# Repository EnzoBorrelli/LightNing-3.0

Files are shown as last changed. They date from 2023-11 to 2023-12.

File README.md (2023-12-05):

# LightNing 3.0

This is the 3rd version of my esp32 + Dualshock4® Rc car, it has the pc made entirely out of smd pieces

## Installation

Download the files. Install KiCad for the PCB and any arduino code editor of your preference (I use Arduino IDE)

## Usage
In the IDE, you must install the ESP32 board and the bluepad 32 library:
[How to install](https://github.com/ricardoquesada/bluepad32#how-to-compile-it)
[original repo](https://github.com/ricardoquesada/bluepad32#bluepad32)

## Contributing

Pull requests are welcome. For major changes, please open an issue first
to discuss what you would like to change.

Please make sure to update tests as appropriate.

## License

[MIT](https://choosealicense.com/licenses/mit/)

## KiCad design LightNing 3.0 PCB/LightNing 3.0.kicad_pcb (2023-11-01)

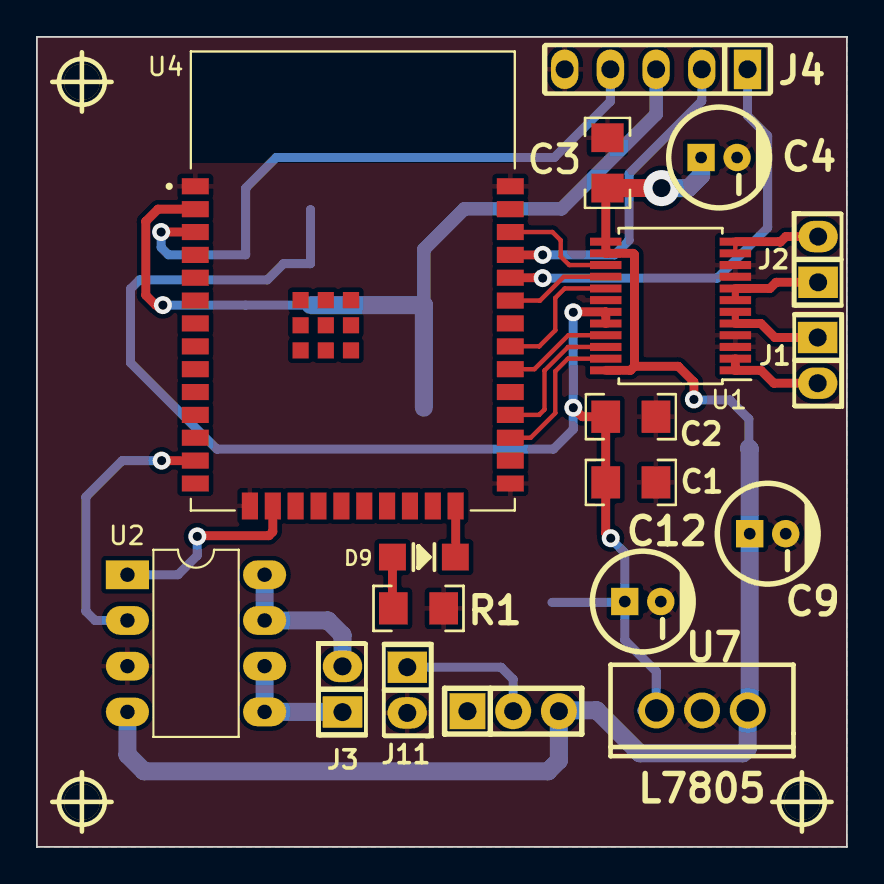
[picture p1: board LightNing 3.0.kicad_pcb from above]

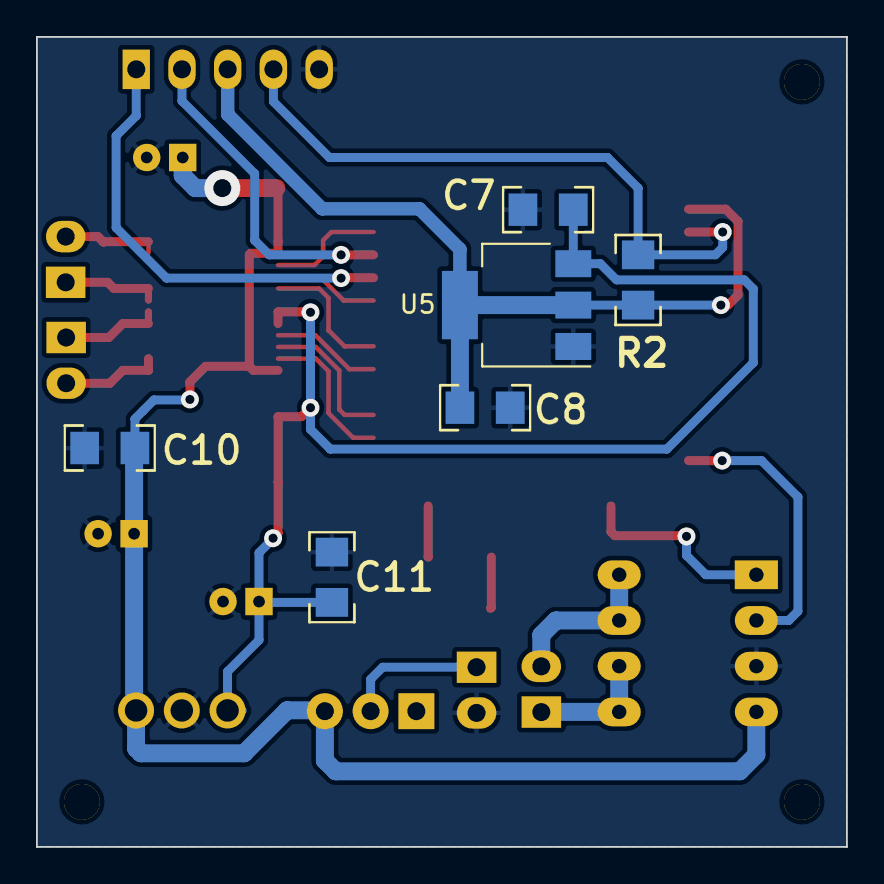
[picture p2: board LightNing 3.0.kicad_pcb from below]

Board: 2 copper layers, 45.0 x 45.0 mm, 27 parts (6 on the bottom side), 24 nets.

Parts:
C1, C3, C7: 10uF; C_1206
C2, C10, C11: 100nF; C_1206
C4: 22uF 25v; CAP_ELEC_5x11mm
C8: 22uF; C_1206
C9: 100uF 25v; CAP_ELEC_5x11mm
C12: 10uF 16v; CAP_ELEC_5x11mm
D9: LED; LED_1206
J1: motor izq; Pin_Header_2
J2: motor der; Pin_Header_2
J3: motor dir; Pin_Header_2
J4: programmer; Pin_Strip_5
J11: batt; Pin_Header_2
R1: 220; R_1206
R2: 10k; R_1206
SW2: SW_SPDT; Pin_Strip_3
U1: TB6612FNG; SSOP-24_5.3x8.2mm_P0.65mm
U2: TA6586; DIP-8
U4: ESP32-WROOM-E; XCVR_ESP32-WROOM-32E__16MB_
U5: AMS1117-3.3; SOT-223-3_TabPin2
U7: L7805; TO-220
hole_2mm, hole_2mm#2, hole_2mm#3: VAL**; hole_2mm

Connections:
+3.3V: C8.1, J4.3, R2.1, U4.2 (3V3), U5.2 (VO)
+5V: C1.1, C2.1, C7.1, C11.1, C12.1, U1.19 (STBY), U1.20 (VCC), U5.3 (VI), U7.3 (OUT)
/IN1: U1.21 (AIN1), U4.30 (GPIO18)
/IN2: U1.22 (AIN2), U4.28 (GPIO17)
/IN3: U1.17 (BIN1), U4.31 (GPIO19)
/IN4: U1.16 (BIN2), U4.33 (GPIO21)
/PWA: U1.23 (PWMA), U4.27 (GPIO16)
/PWB: U1.15 (PWMB), U4.36 (GPIO22)
/en: J4.4, R2.2, U4.3 (EN/CHIP_PU)
/pin_dirA: U2.2 (FI), U4.13 (MTMS/GPIO14/ADC2_CH6)
/pin_dirB: U2.1 (BI), U4.16 (MTCK/GPIO13/ADC2_CH4)
/rx: J4.1, U4.34 (U0RXD/GPIO3)
/tx: J4.2, U4.35 (U0TXD/GPIO1)
GND: C1.2, C2.2, C3.2, C4.2, C7.2, C8.2, C9.2, C10.2, C11.2, C12.2, J4.5, J11.2, R1.2, U1.3 (PGND1), U1.4 (PGND1), U1.9 (PGND2), U1.10 (PGND2), U1.18 (GND), U2.3 (GND), U4.1 (GND), U4.15 (GND), U4.25 (GPIO0/BOOT/ADC2_CH1), U4.38 (GND), U5.1 (GND), U7.2 (GND)
unnamed: D9.2 (A), U4.24 (ADC2_CH2/GPIO2)
unnamed: D9.1 (K), R1.1
unnamed: J1.1, U1.5 (AO2), U1.6 (AO2)
unnamed: J1.2, U1.1 (AO1), U1.2 (AO1)
unnamed: J2.1, U1.7 (BO2), U1.8 (BO2)
unnamed: J2.2, U1.11 (BO1), U1.12 (BO1)
unnamed: J3.1, U2.5 (FO), U2.6 (FO)
unnamed: J3.2, U2.7 (BO), U2.8 (BO)
unnamed: J11.1, SW2.2 (B)
VCC: C3.1, C4.1, C9.1, C10.1, SW2.3 (C), U1.13 (VM2), U1.14 (VM3), U1.24 (VM1), U2.4 (VCC), U7.1 (IN)

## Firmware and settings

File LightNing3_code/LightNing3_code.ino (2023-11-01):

/*
----LightNing 3.0 code V1----

codigo de control del RC-car, comunicando el NODEMcu-esp32s con DualSHock4®

- ByEnder|2023

*/
#include <Adafruit_NeoPixel.h>
#include <Bluepad32.h>

//Librerias propias
#include "Defines.h"
#include "motorClass.h"

#define DEBUG true
//constantes de giro
#define JOYSTICK_DEADZONE 70
#define PWM_LOST 50

// constante de velocidad
#define NORMAL_SPEED 200

//inicializacion de los objetos de los motores
Motor *LadoIZQ = new Motor(PWM_MOTOR_A, PIN_PWM1, PIN_MOTOR_A1, PIN_MOTOR_A2, FREQ, RES);
Motor *LadoDER = new Motor(PWM_MOTOR_B, PIN_PWM2, PIN_MOTOR_B1, PIN_MOTOR_B2, FREQ, RES);

GamepadPtr myGamepads[BP32_MAX_GAMEPADS];

// This callback gets called any time a new gamepad is connected.
// Up to 4 gamepads can be connected at the same time.
void onConnectedGamepad(GamepadPtr gp) {
  bool foundEmptySlot = false;
  for (int i = 0; i < BP32_MAX_GAMEPADS; i++) {
    if (myGamepads[i] == nullptr) {
      Serial.printf("CALLBACK: Gamepad is connected, index=%d\n", i);
      // Additionally, you can get certain gamepad properties like:
      // Model, VID, PID, BTAddr, flags, etc.
      GamepadProperties properties = gp->getProperties();
      Serial.printf("Gamepad model: %s, VID=0x%04x, PID=0x%04x\n",
                    gp->getModelName().c_str(), properties.vendor_id,
                    properties.product_id);
      myGamepads[i] = gp;
      foundEmptySlot = true;
      break;
    }
  }
  if (!foundEmptySlot) {
    Serial.println(
      "CALLBACK: Gamepad connected, but could not found empty slot");
  }
}

void onDisconnectedGamepad(GamepadPtr gp) {
  bool foundGamepad = false;

  for (int i = 0; i < BP32_MAX_GAMEPADS; i++) {
    if (myGamepads[i] == gp) {
      Serial.printf("CALLBACK: Gamepad is disconnected from index=%d\n", i);
      myGamepads[i] = nullptr;
      foundGamepad = true;
      break;
    }
  }

  if (!foundGamepad) {
    Serial.println(
      "CALLBACK: Gamepad disconnected, but not found in myGamepads");
  }
}
// Arduino setup function. Runs in CPU 1
void setup() {
  ledNeo.begin();
  if (DEBUG) Serial.begin(115200);
  Serial.printf("Firmware: %s\n", BP32.firmwareVersion());
  const uint8_t *addr = BP32.localBdAddress();
  Serial.printf("BD Addr: %2X:%2X:%2X:%2X:%2X:%2X\n", addr[0], addr[1], addr[2],
                addr[3], addr[4], addr[5]);

  // Setup the Bluepad32 callbacks
  BP32.setup(&onConnectedGamepad, &onDisconnectedGamepad);

  // "forgetBluetoothKeys()" should be called when the user performs
  // a "device factory reset", or similar.
  // Calling "forgetBluetoothKeys" in setup() just as an example.
  // Forgetting Bluetooth keys prevents "paired" gamepads to reconnect.
  // But might also fix some connection / re-connection issues.
  BP32.forgetBluetoothKeys();
}

// Arduino loop function. Runs in CPU 1
void loop() {
  // This call fetches all the gamepad info from the NINA (ESP32) module.
  // Just call this function in your main loop.
  // The gamepads pointer (the ones received in the callbacks) gets updated
  // automatically.
  BP32.update();
  ledNeo.clear();
  // It is safe to always do this before using the gamepad API.
  // This guarantees that the gamepad is valid and connected.
  for (int i = 0; i < BP32_MAX_GAMEPADS; i++) {
    GamepadPtr myGamepad = myGamepads[i];

    if (myGamepad && myGamepad->isConnected()) {
      myGamepad->setColorLED(white[0], white[1], white[2]);
      if (myGamepad->throttle()) {
        LadoIZQ->MotorUp(NORMAL_SPEED);
        LadoDER->MotorUp(NORMAL_SPEED);
        myGamepad->setColorLED(green[0], green[1], green[2]);
        if (DEBUG) Serial.println("pa lante");
      }
      if (myGamepad->brake()) {
        LadoIZQ->MotorDown(NORMAL_SPEED);
        LadoDER->MotorDown(NORMAL_SPEED);
        myGamepad->setColorLED(orange[0], orange[1], orange[2]);
        if (DEBUG) Serial.println("pa atras");
      }
      if (myGamepad->axisX()) {
        if (myGamepad->axisX() < -JOYSTICK_DEADZONE) {
          LadoIZQ->MotorUp(NORMAL_SPEED - PWM_LOST);
          LadoDER->MotorUp(NORMAL_SPEED);
          myGamepad->setColorLED(blue[0], blue[1], blue[2]);
          if (DEBUG) Serial.println("giro izq");
        }
        if (myGamepad->axisX() > JOYSTICK_DEADZONE) {
          LadoIZQ->MotorUp(NORMAL_SPEED);
          LadoDER->MotorUp(NORMAL_SPEED - PWM_LOST);
          myGamepad->setColorLED(cyan[0], cyan[1], cyan[2]);
          if (DEBUG) Serial.println("giro der");
        }
      }
      if (myGamepad->buttons() == 0x0010) {
        LadoIZQ->MotorDown(NORMAL_SPEED);
        LadoDER->MotorUp(NORMAL_SPEED);
        myGamepad->setColorLED(purple[0], purple[1], purple[2]);
        if (DEBUG) Serial.println("rotacion izq");
      }
      if (myGamepad->buttons() == 0x0020) {
        LadoIZQ->MotorUp(NORMAL_SPEED);
        LadoDER->MotorDown(NORMAL_SPEED);
        myGamepad->setColorLED(violet[0], violet[1], violet[2]);
        if (DEBUG) Serial.println("rotacion der");
      }
      if (myGamepad->x()) {
        LadoIZQ->MotorStop();
        LadoDER->MotorStop();
        myGamepad->setColorLED(red[0], red[1], red[2]);
      }
    }
  }

  // The main loop must have some kind of "yield to lower priority task" event.
  // Otherwise the watchdog will get triggered.
  // If your main loop doesn't have one, just add a simple `vTaskDelay(1)`.
  // Detailed info here:
  // https://stackoverflow.com/questions/66278271/task-watchdog-got-triggered-the-tasks-did-not-reset-the-watchdog-in-time

  // vTaskDelay(1);
  delay(150);
}

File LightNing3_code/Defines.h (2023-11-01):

//pines IN de los motores
#define PIN_MOTOR_A1 16
#define PIN_MOTOR_A2 17
#define PIN_MOTOR_B1 18
#define PIN_MOTOR_B2 19
#define PIN_PWM1 19
#define PIN_PWM2 19

//canales PWM
#define PWM_MOTOR_A 0
#define PWM_MOTOR_B 1

#define FREQ 10000
#define RES 8

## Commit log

2023-05-15 uno cambio lokos
    [LightNing 3.0.kicad_pcb, LightNing 3.0.kicad_sch]
2023-05-18 agregado el cargador
    [cargador-cargador.kicad_pcb, cargador-cargador.kicad_sch]
2023-05-19 little responsive
    [cargador-cargador.kicad_pcb, cargador-cargador.kicad_sch, cargador-cargador.step]
2023-10-30 pcb terminado
    [LightNing 3.0.kicad_pcb, LightNing 3.0.kicad_sch]
2023-11-01 update 1 november
    [LightNing 3.0.kicad_pcb, LightNing 3.0.kicad_sch, cargador-cargador.kicad_pcb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]
